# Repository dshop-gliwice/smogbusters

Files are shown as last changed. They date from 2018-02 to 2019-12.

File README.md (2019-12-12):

# smogbusters
Air monitoring project

Links:
 - particulate matter (PM) map: http://smogbusters.org/
 - charts: http://grafana.smogbusters.org/dashboard/db/measurements?refresh=10s&orgId=1
 - list of components: [bom.md](./docs/bom.md)

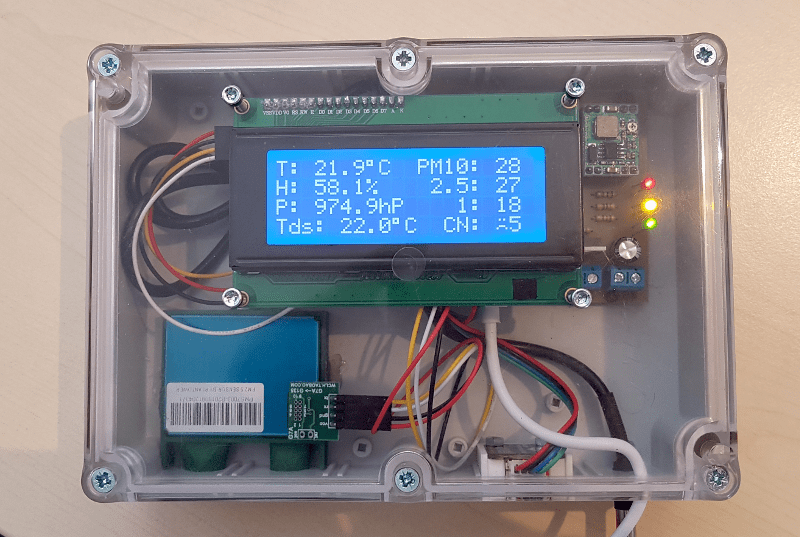
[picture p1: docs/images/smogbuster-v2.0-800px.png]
smogbusters-prototype


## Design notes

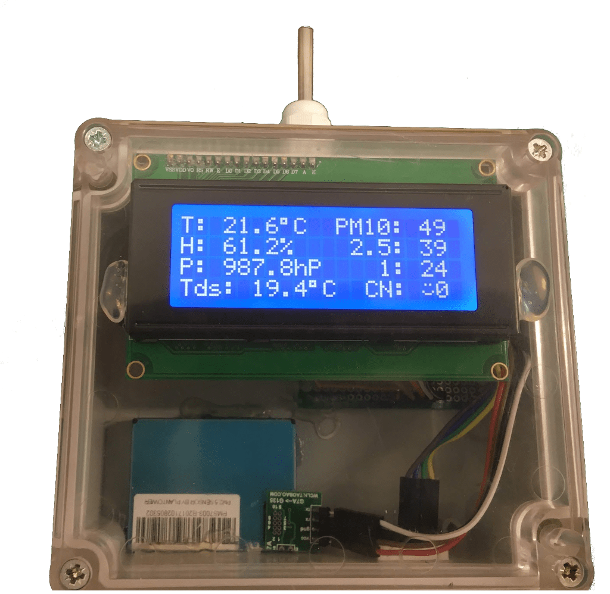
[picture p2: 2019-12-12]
docs/images/smogbuster-prototype.png

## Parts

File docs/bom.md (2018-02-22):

# smogbusters
Air monitoring project

* NodeMCU
  * https://www.aliexpress.com/item/1PCS-New-Wireless-Module-NodeMcu-Lua-WIFI-Internet-of-Things-development-board-based-ESP8266-with-pcb/32786565171.html
  * https://botland.com.pl/moduly-wifi/4450-modul-wifi-esp8266-nodemcu-v2-4mb.html
  * https://kamami.pl/moduly-wifi/559667-modul-z-esp8266-nodemcu.html

* Case
  * https://maszczyk.pl/pokaz_produkt/obudowy-hermetyczne-z-74.html

* Mosfet IRLZ44N
  * https://www.aliexpress.com/item/10PCS-IRLZ44N-IRLZ44-TO-220-TO220-IRLZ44NPBF/32845164480.html
  * https://botland.com.pl/n-mosfet/1950-n-mosfet-irlz44n-tht.html?search_query=IRLZ44N&results=1

* DC Power Supply Socket Female - 5.5 x 2.1mm
  * https://www.aliexpress.com/item/10Pcs-5-5-x-2-1mm-DC-Power-Supply-Jack-Socket-Female-Panel-Mount-3-Pin/32826223303.html
  * https://botland.com.pl/przewody-i-zlacza-zasilajace/9352-gniazdo-dc-55-x-21mm-do-obudowy.html

* 15 Pin Female Single Row Straight Header Strip 2.54mm Pitch  
  * https://www.aliexpress.com/snapshot/0.html?productId=1801736539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

* ARK connector
  * https://www.aliexpress.com/item/20pcs-KF301-2-Pin-Screw-Terminal-Block-Connector-5mm-Pitch-B/32735166786.html
  * https://botland.com.pl/zlacza-ark/810-zlacze-kf301-raster-5-mm-2-pin-.html

* Wires
  * https://botland.com.pl/przewody-polaczeniowe/2713-przewod-zensko-zenski-4-pin-20cm.html

* Power supply
  * https://www.aliexpress.com/item/S103-1pc-New-AC-100-240V-to-DC-5V-2A-Switching-Power-Supply-Converter-Adapter-EU/2002134601.html

* BME280
  * https://www.aliexpress.com/item/BME280-Digital-Sensor-Temperature-Humidity-Barometric-Pressure-Sensor-Breakout-Module-BME280-I2C-SPI-1-8-5V/32835514108.html
  * https://botland.com.pl/czujniki-temperatury/165-czujnik-temperatury-ds18b20-cyfrowy-1-wire-tht.html
  * https://kamami.pl/czujniki-temperatury/565661-bme280-czujnik-temperatury-wilgotnosci-oraz-barometr-modul-gravity-sen0236.html

* DS18B20
  * https://www.aliexpress.com/item/new-and-original-DS18B20-18B20-TO-92-3-Digital-Thermometer-Sensor/32716051460.html
  * https://kamami.pl/temperatury/138578-ds18b20.html

* PLANTOWER Laser DUST SENSOR PMS7003  
  * https://www.aliexpress.com/item/PLANTOWER-Laser-PM2-5-DUST-SENSOR-PMS7003-G7-High-precision-laser-dust-concentration-sensor-digital-dust/32639894148.html
  * https://kamami.pl/czujniki-gazow/564008-plantower-pms7003-laserowy-czujnik-pylu-pm25.html

* IDC adapter
  * https://kamami.pl/zlacza-inne/564553-adapter-idc10-127mm-na-zlacze-254mm-dla-czujnika-pms7003.html

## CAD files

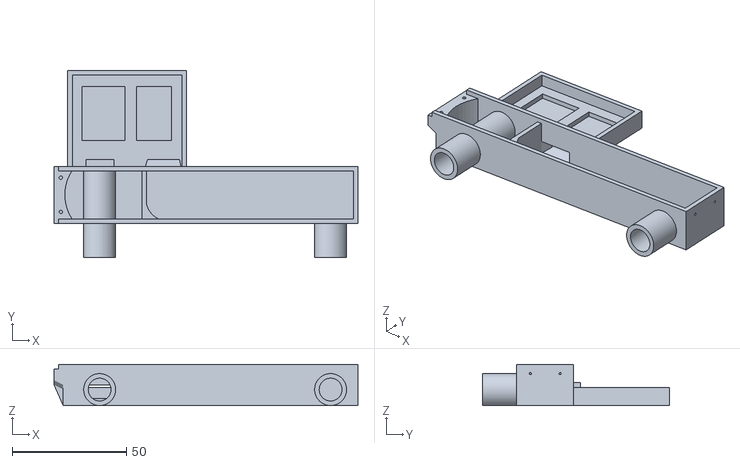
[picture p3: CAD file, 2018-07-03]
parts/Smog_buster_v1_35_main.stl
133.2 x 82.0 x 18.0

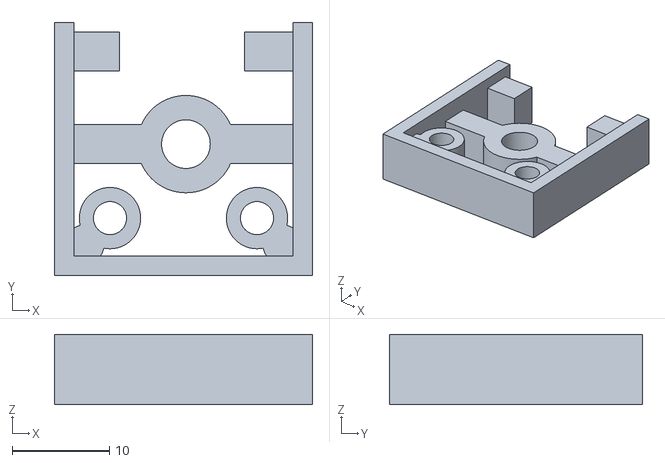
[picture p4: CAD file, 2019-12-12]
parts/bme280-dfrobot.stl
26.5 x 26.0 x 7.20

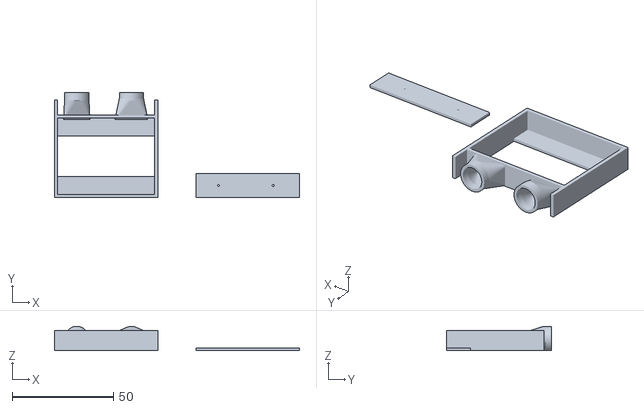
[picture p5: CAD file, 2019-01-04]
parts/pms7003.stl
121.0 x 52.0 x 12.0

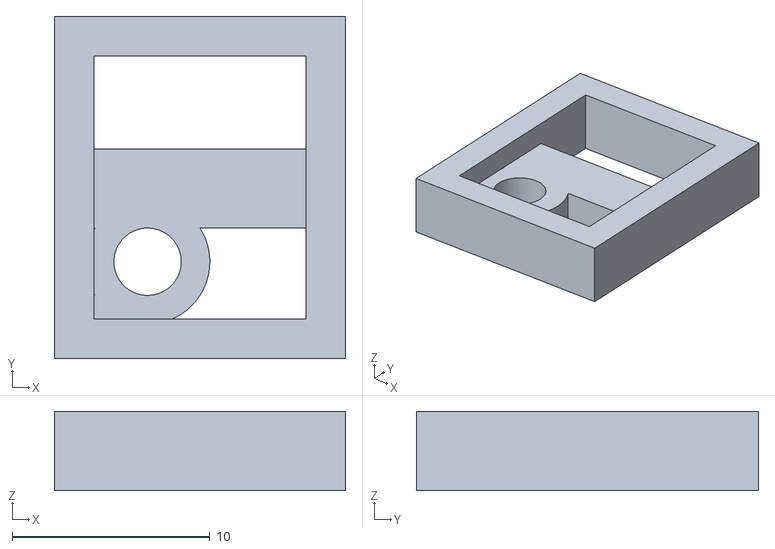
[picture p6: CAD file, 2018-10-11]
parts/bme280-narrow.stl
14.7 x 17.3 x 4.00

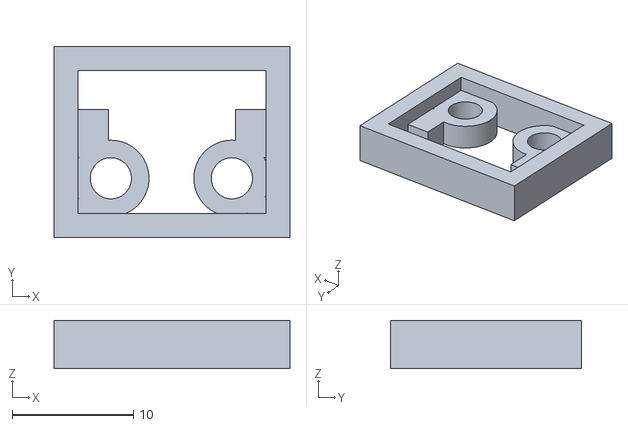
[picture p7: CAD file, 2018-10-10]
parts/bme280-wide.stl
19.5 x 15.8 x 4.00

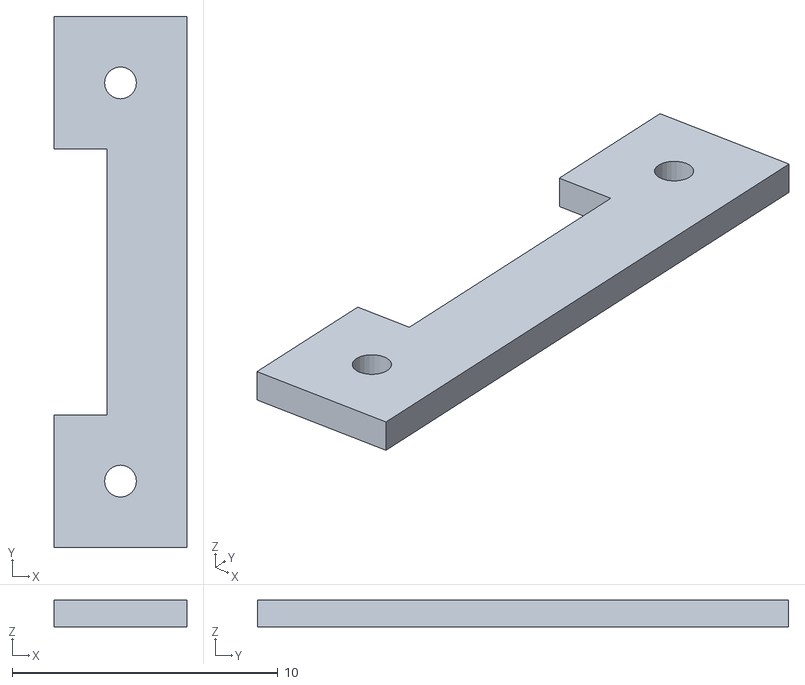
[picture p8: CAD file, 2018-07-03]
parts/Smog_buster_v1_35_zaczep.stl
5.00 x 20.0 x 1

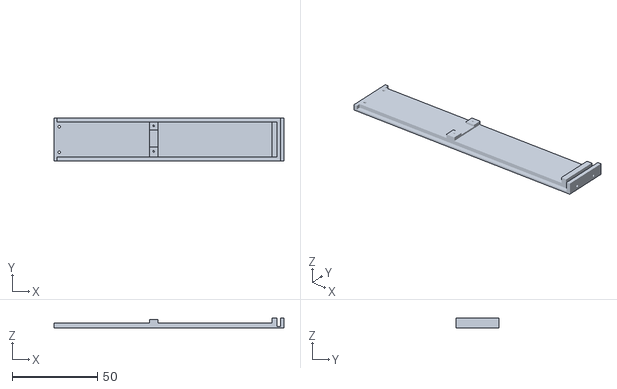
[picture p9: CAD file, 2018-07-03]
parts/Smog_buster_v1_35_klapka.stl
135.0 x 25.0 x 6.00

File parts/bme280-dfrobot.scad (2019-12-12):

$fn=64;

sHeight=7.2;
zOffset=0;

module screwMount(){
  difference(){
      cylinder(h = sHeight-1.5,
           d = 6.3  ,
           center = false);
      cylinder(h = sHeight,
           d = 3.4,
           center = false);
  } 
}

module spacer(){
    cube([5.5, 4, sHeight-1.5], false);  
}

module screwMountFill(){
    cylinder(h = sHeight-1.5,
           d = 4,
           center = false);
}


module main(){
  union(){

   //screw mounts
   translate([5.7, 5.9, zOffset])
     screwMount();
   translate([20.8, 5.9, zOffset])
     screwMount();

    //sensor channel
    difference(){
     union(){
       translate([1.2, 11.5, zOffset])
         cube([24,4,sHeight-2.5],false);
       translate([13.5, 13.5, zOffset])
         cylinder(h = sHeight-2.5,
           d = 10  ,
           center = false);
      }
      translate([13.5, 13.5, zOffset])
        cylinder(h = sHeight-1.3,
           d = 5,
           center = false);
    } 


   //screw mounts connections
   translate([3.1, 3.2, zOffset])
    screwMountFill();
   translate([23.4, 3.2, zOffset])
    screwMountFill();
    
   //back spacers
   translate([1.2, 21, zOffset])
    spacer();
   translate([19.5, 21, zOffset])
    spacer();
    
   //front wall
   translate([0, 0, zOffset])
    cube([26,2,sHeight],false);

   //side walls
   translate([0, 0, zOffset])
    cube([2, 26, sHeight],false);    
   translate([24.5, 0, zOffset])
    cube([2, 26, sHeight],false); 
  }  
}


main();

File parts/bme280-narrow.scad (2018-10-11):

$fn=64;

wHeight=4; //wall height
wThick=2; //wall thickness
bWidth=10.7; //board width
bHeight=13.3; //board height

module screwMount(){
  difference(){
    cylinder(h = wHeight-1.5,
             d = 6.3,
        center = false);
    cylinder(h = wHeight-1.3,
             d = 3.4,
        center = false);
  } 
}

module spacer(){
  cube([bWidth, 4, wHeight-1.5],false);  
}

module screwMountFill(){
  cylinder(h = wHeight-1.5,
           d = 2,
      center = false);
}

module main(){
  union(){
    //screw mounts
    translate([wThick+2.7, wThick+2.9, 0])
      screwMount();

    //screw mounts connections
    translate([wThick+0.6, wThick+0.4, 0])
      screwMountFill();
        
    //back spacer
    translate([wThick, wThick+4.6, 0])
      spacer();

    //front wall
    translate([0, 0, 0])
      cube([wThick*2+bWidth, wThick, wHeight], false);
    //back wall
    translate([0, wThick+bHeight, 0])
      cube([wThick*2+bWidth, wThick, wHeight], false);

    //side walls
    translate([0, 0, 0])
      cube([wThick, wThick+bHeight, wHeight], false);    
    translate([wThick+bWidth, 0, 0])
      cube([wThick, wThick+bHeight, wHeight], false);
  }  
}


main();

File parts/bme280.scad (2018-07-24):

$fn=64;

sHeight=7.2;

module screwMount(){
  difference(){
      cylinder(h = sHeight-1.5,
           d = 6.3,
           center = false);
      cylinder(h = sHeight-1.3,
           d = 3.4,
           center = false);
  } 
}

module spacer(){
    cube([5.5,4,sHeight-1.5],false);  
}

module screwMountFill(){
    cylinder(h = sHeight-1.5,
           d = 4,
           center = false);
}


module main(){
  union(){
   //screw mounts
   translate([5.4, 5.6, 0])
    screwMount();
   translate([20.6, 5.6, 0])
    screwMount();
    
   //screw mounts connections
   translate([2.9, 3, 0])
    screwMountFill();
   translate([23.1, 3, 0])
    screwMountFill();
    
   //back spacers
   translate([1.2,21,0])
    spacer();
   translate([19,21,0])
    spacer();
    
   //front wall
   translate([0,0,0])
    cube([26,2,sHeight],false);

   //side walls
   translate([0,0,0])
    cube([2,26,sHeight],false);    
   translate([24,0])
    cube([2,26,sHeight],false);
  }  
}


main();

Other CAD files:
parts/bme280-wide.scad
parts/pms7003.scad

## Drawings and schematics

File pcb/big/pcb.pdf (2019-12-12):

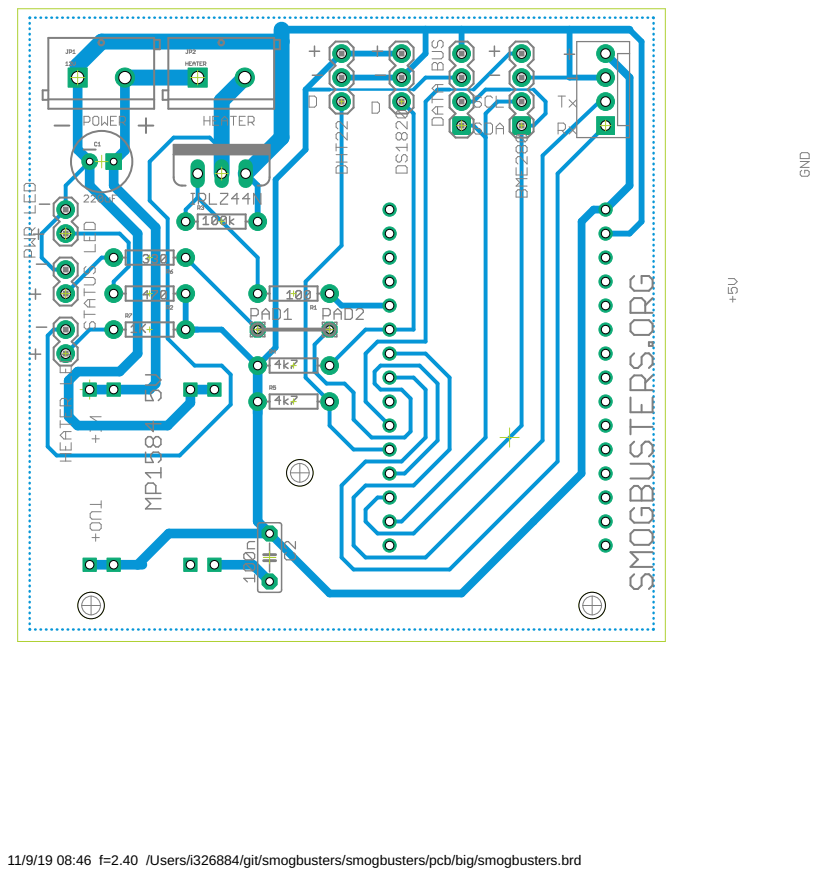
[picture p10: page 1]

11/9/19 08:46 f=2.40 /Users/i326884/git/smogbusters/smogbusters/pcb/big/smogbusters.brd

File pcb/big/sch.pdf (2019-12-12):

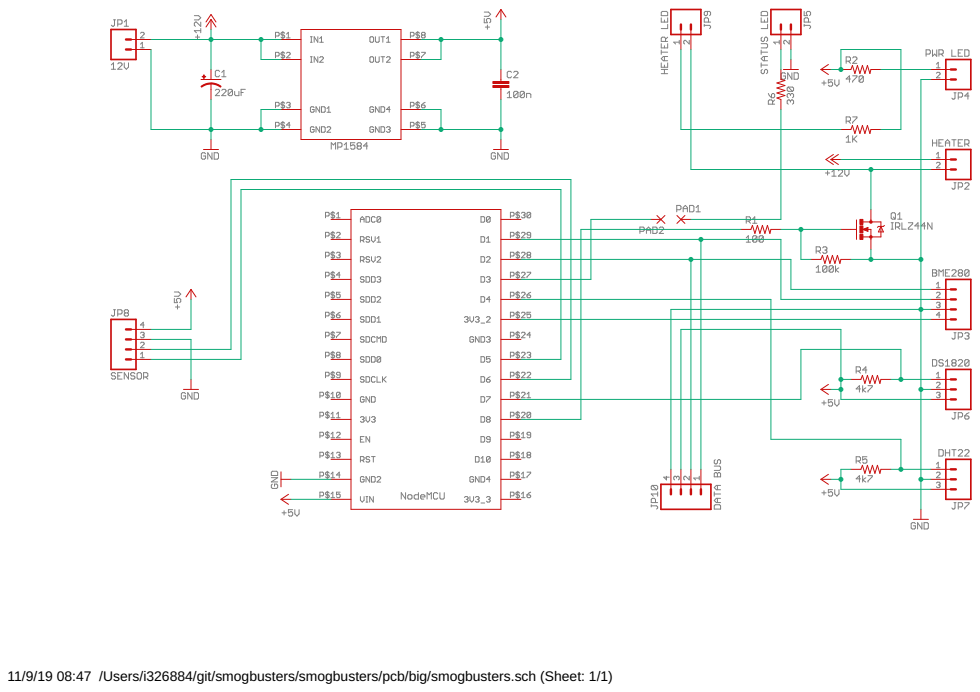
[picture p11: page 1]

11/9/19 08:47 /Users/i326884/git/smogbusters/smogbusters/pcb/big/smogbusters.sch (Sheet: 1/1)

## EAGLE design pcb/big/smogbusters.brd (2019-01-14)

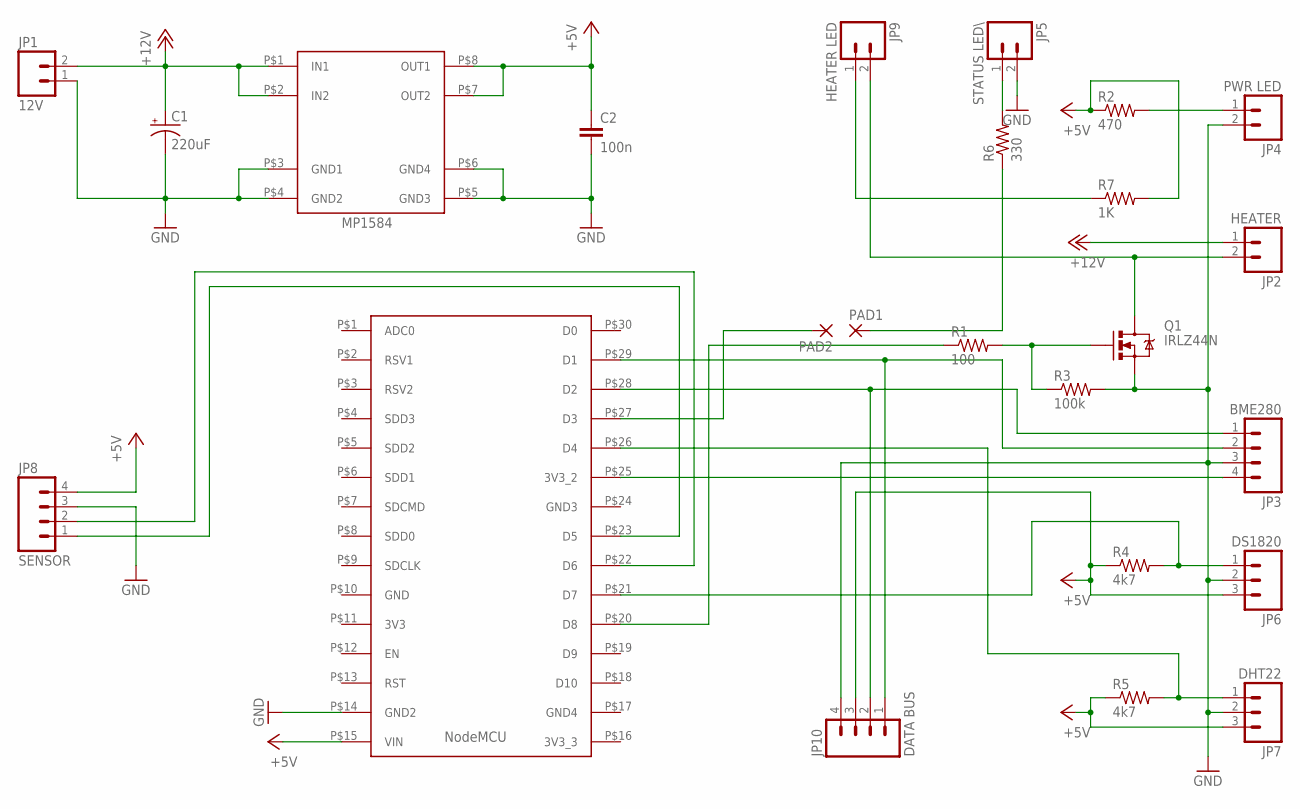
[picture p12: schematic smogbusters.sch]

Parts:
C1: 220uF; CPOL-RADIAL-100UF-25V
C2: 100n; C5B2.5
JP1: 12V; SCREWTERMINAL-5MM-2
JP2: HEATER; SCREWTERMINAL-5MM-2
JP3: BME280; 1X04
JP4: PWR LED; 1X02
JP5: STATUS LED\; 1X02
JP6: DS1820; 1X03
JP7: DHT22; 1X03
JP8: SENSOR; MOLEX-1X4
JP9: HEATER LED; 1X02
JP10: DATA BUS; 1X04
PAD1, PAD2: 1,6/0,8
Q1: IRLZ44N; TO220V
R1: 100; AXIAL-0.3
R2: 470; AXIAL-0.3
R3: 100k; AXIAL-0.3
R4, R5: 4k7; AXIAL-0.3
R6: 330; AXIAL-0.3
R7: 1K; AXIAL-0.3
U$1: NODEMCU
U$2: MP1584

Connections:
+5V: C2.1, JP6.3, JP7.3, JP8.4, JP10.3, R2.P$1 (1), R4.P$1 (1), R5.P$1 (1), R7.P$2 (2), U$1.P$15 (VIN), U$2.P$7 (OUT2), U$2.P$8 (OUT1)
+12V: C1.1 (+), JP1.2, JP2.1, U$2.P$1 (IN1), U$2.P$2 (IN2)
GND: C1.2 (-), C2.2, JP1.1, JP3.3, JP4.2, JP5.2, JP6.2, JP7.2, JP8.3, JP10.4, Q1.3 (S), R3.P$2 (2), U$1.P$14 (GND2), U$2.P$3 (GND1), U$2.P$4 (GND2), U$2.P$5 (GND3), U$2.P$6 (GND4)
unnamed: JP2.2, JP9.2, Q1.2 (D)
unnamed: JP6.1, R4.P$2 (2), U$1.P$21 (D7)
unnamed: Q1.1 (G), R1.P$2 (2), R3.P$1 (1)
unnamed: JP5.1, R6.P$2 (2)
unnamed: JP3.4, U$1.P$25 (3V3_2)
unnamed: JP8.1, U$1.P$23 (D5)
unnamed: JP8.2, U$1.P$22 (D6)
unnamed: R1.P$1 (1), U$1.P$20 (D8)
unnamed: JP7.1, R5.P$2 (2), U$1.P$26 (D4)
unnamed: PAD1.1, R6.P$1 (1)
unnamed: JP9.1, R7.P$1 (1)
unnamed: PAD2.1, U$1.P$27 (D3)
unnamed: JP4.1, R2.P$2 (2)
unnamed: JP3.1, JP10.2, U$1.P$28 (D2)
unnamed: JP3.2, JP10.1, U$1.P$29 (D1)

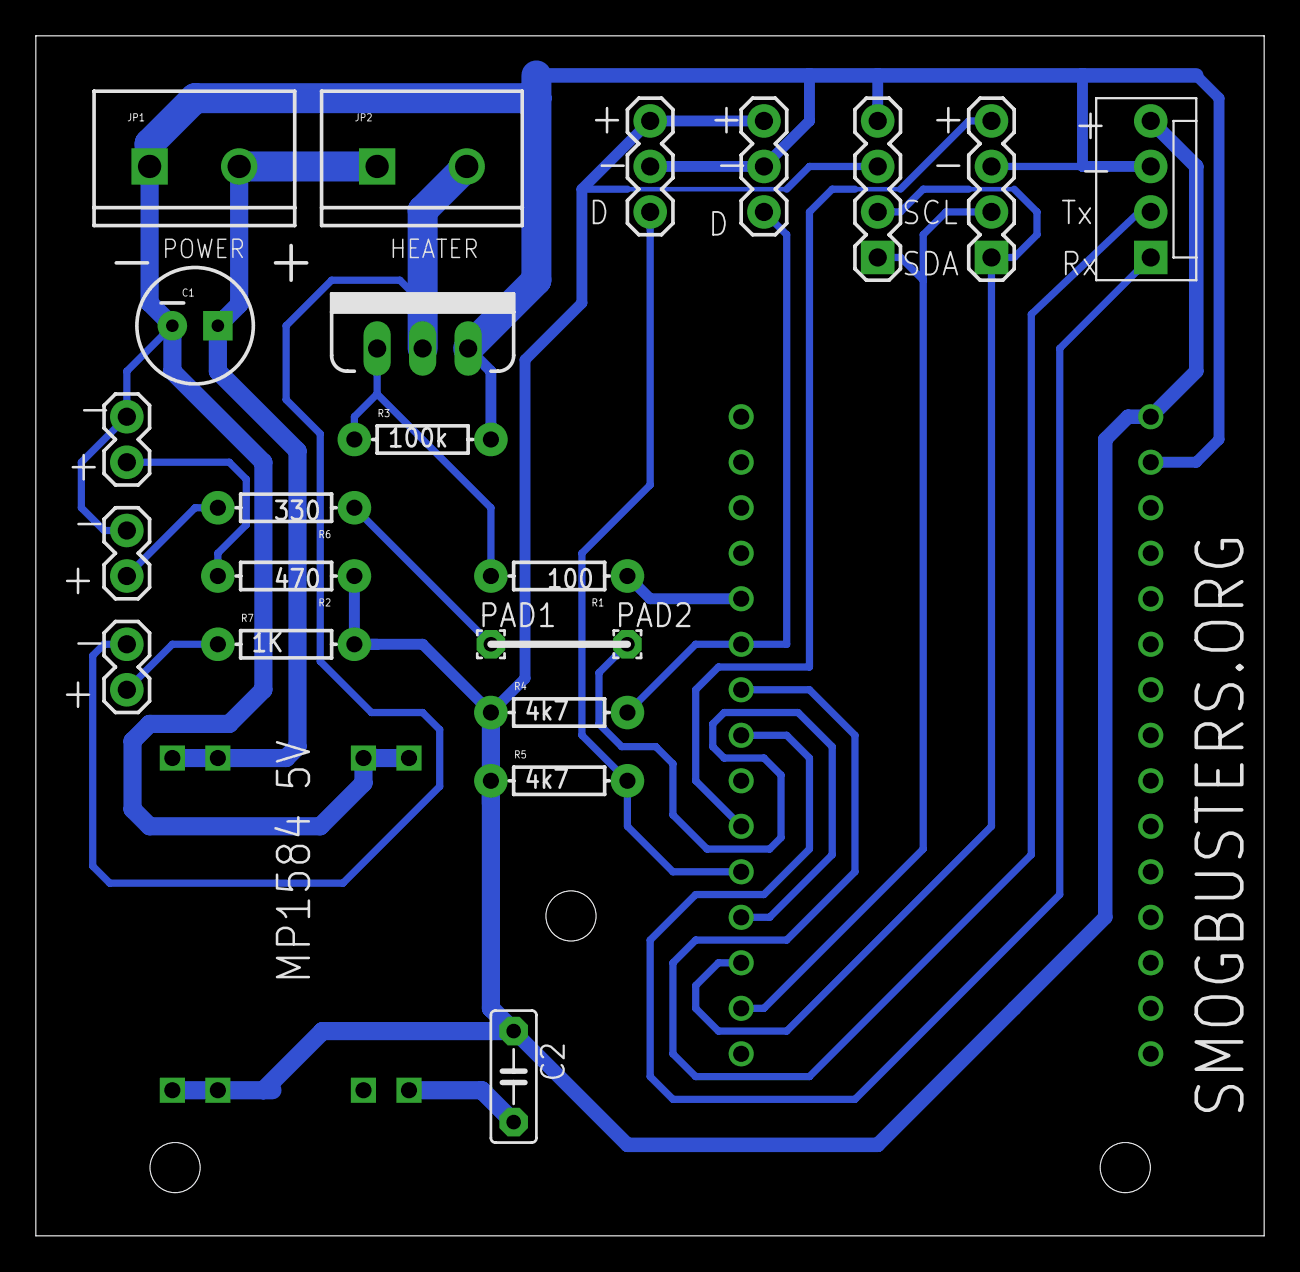
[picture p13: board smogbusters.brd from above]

Board: 1 copper layer, 68.6 x 67.0 mm, 24 parts (1 on the bottom side), 18 nets.

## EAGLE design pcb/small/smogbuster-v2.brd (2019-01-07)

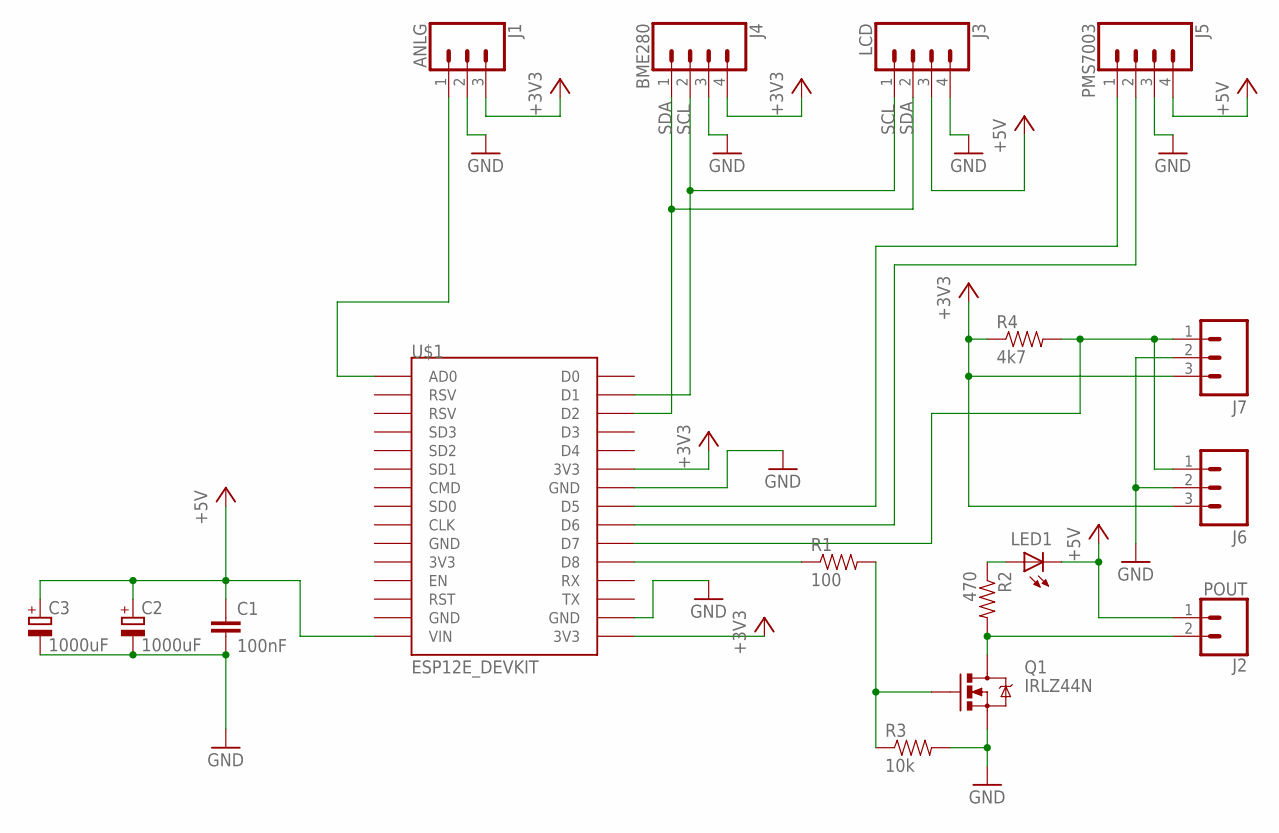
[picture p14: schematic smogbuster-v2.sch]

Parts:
C1: 100nF; CAP-PTH-5MM
C2, C3: 1000uF; E2,5-7
J1: ANLG; 1X03
J2: POUT; 1X02
J3: LCD; 1X04
J4: BME280; 1X04
J5: PMS7003; 1X04
J6, J7: M03PTH; 1X03
LED1: LED3MM
Q1: IRLZ44N; TO220V
R1: 100; AXIAL-0.3
R2: 470; AXIAL-0.3
R3: 10k; AXIAL-0.3
R4: 4k7; AXIAL-0.3
U$1: ESP12E_DEVKIT

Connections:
+3V3: J1.3, J4.4, J6.3, J7.3, R4.P$1 (1), U$1.3V3@1 (3V3), U$1.3V3@2 (3V3)
+5V: C1.1, C2.+, C3.+, J2.1, J3.3, J5.4, LED1.K (C), U$1.VIN
DQ: J6.1, J7.1, R4.P$2 (2), U$1.D7
GND: C1.2, C2.-, C3.-, J1.2, J3.4, J4.3, J5.3, J6.2, J7.2, Q1.3 (S), R3.P$2 (2), U$1.GND@2 (GND), U$1.GND@3 (GND)
unnamed: J2.2, Q1.2 (D), R2.P$2 (2)
unnamed: Q1.1 (G), R1.P$2 (2), R3.P$1 (1)
unnamed: J1.1, U$1.AD0
unnamed: R1.P$1 (1), U$1.D8
unnamed: LED1.A, R2.P$1 (1)
RX: J5.1, U$1.D5
SCL: J3.1, J4.2, U$1.D1
SDA: J3.2, J4.1, U$1.D2
TX: J5.2, U$1.D6

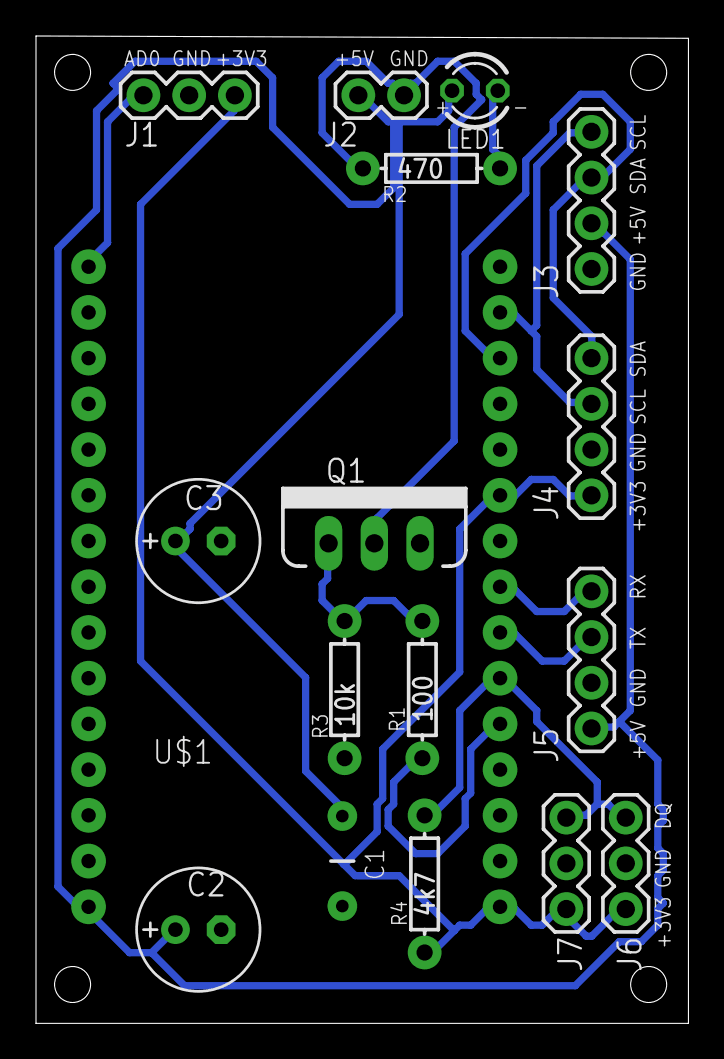
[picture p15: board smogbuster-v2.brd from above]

Board: 1 copper layer, 36.2 x 54.9 mm, 17 parts (0 on the bottom side), 13 nets.

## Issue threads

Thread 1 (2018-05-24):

List of issues with PCB

adamwalach, 2018-05-24:
- DC2DC converter is mounted upside-down
- connectors for BME280, DS1820, DHT22 are covered by nodemcu
- change value of resistors green led (power) - 470, yellow (status) - 470
- fix pins labels for BME280
- change pin for status LED to D3 - we cannot use A0 as a digital output
- for the "DATA BUS" connector use the same pins as for BME280 (D1, D2)

adamwalach, 2018-10-02:
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

Closed 2019-12-16.

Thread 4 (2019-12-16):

Control LCD backlight with motion sensor

adamwalach, 2019-12-16:
With sensor like [HC-SR501](https://www.aliexpress.com/item/4000202877086.html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,searchweb201602_3,searchweb201603_53) or similar we could control the LCD backlight. That would make our device more friendly for in-door use.
AC:
- connect HC-SR501 to an unused input pin from NodeMCU
- add support for it in the code so every time motion is detected the LCD backlight will be turned on (by a command - we do not need to add any additional hardware)

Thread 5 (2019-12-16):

Turn ON particulate matter sensor only when it is needed

adamwalach, 2019-12-16:
PMS 7003 (particulate matter sensor) should be turned on/powered on only when its needed - this way we can extend lifetime of the laser diode.
We could use the high power output that was originally designed to control heater. The problem is that it connects to the ground terminal. That may not work.

AC:
 - PMS7003 is powered on (diode and fan) only when it is needed - before the measurement is about to be taken (or with some additional delay so it provides a stable readout)

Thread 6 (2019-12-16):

Protect input and output channels of particulate matter sensor

adamwalach, 2019-12-16:
Input and output channels are about 10 mm in size - that is enough for some insects to get inside and build a warm and cozy nest. We would like to avoid that.
We could use a piece of [mosquito net](https://www.castorama.pl/siatka-na-okno-bros-fx-100-x-100-cm-czarna-id-44377.html) and 3d-printed adapter to cover the channels.

AC:
- channels are protected
- no regression to sensor sensitivity

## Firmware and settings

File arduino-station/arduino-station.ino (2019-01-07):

#include <EEPROM.h>
#include <ESP8266WiFi.h>
#include <ESP8266HTTPClient.h>
#include "Timer.h"


#define READ_CYCLE 10000

#define UUID_LENGTH 25
#define FW_VERSION "18.12.03-a"

Timer timer;

struct MeasurementId {
  char uuid[UUID_LENGTH];
  char sensors [10];      
};
  
struct MeasurementData {
  float temp;
  float humidity;
  float pressure;
  int pm25;
  int pm10;
  int pm1;
  float DStemp;
  char firmware [15];
};

struct Measurement {
  char version [5];
  struct MeasurementId id;
  struct MeasurementData data;
};

struct PmsData {
  int pm1;
  int pm25;
  int pm10;
};

void setup() {
  randomSeed(analogRead(0));
  EEPROM.begin(512);
  initializeSerial();
  checkContext();
  initializeStatusLed();
  initializeHeater();
  initializeSensors();
  initializeLCD();
  initClient();
  initOTA();
}

void loop() {
  serialLoop();
  timer.update();
}

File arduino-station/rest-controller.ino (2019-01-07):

#include <ESP8266WiFi.h>
#include <ESP8266HTTPClient.h>
#include <ArduinoJson.h>

const char* gatewayUrl = "http://api.smogbusters.org/api/measurement";

unsigned long sendCount = 0;
unsigned long sendCountFailed = 0;

void initClient() {
    Serial.println();
    Serial.print("Gateway url: ");
    Serial.println(gatewayUrl);
    Serial.print("MAC: ");
    Serial.println(WiFi.macAddress());
    Serial.print("FW version: ");
    Serial.println(FW_VERSION);

    Serial.print("Connecting to ");
    Serial.println(ctx.wifiSSID);

    Serial.flush();

    WiFi.mode(WIFI_STA);
    WiFi.begin(ctx.wifiSSID, ctx.wifiPasswd);

    int i=0;
    while (WiFi.status() != WL_CONNECTED && i<40) {
      blinkStatusLed();
      Serial.print(".");
      i++;
    }
    
    if (WiFi.status() == WL_CONNECTED){
      Serial.println("WIFI connected");
      Serial.print("IP address: ");
      Serial.println(WiFi.localIP());
      enableStatusLed();
    }else{
      Serial.println("WIFI is NOT connected");
    }
}

bool sendMeasurement(Measurement * msr, size_t memSize) {
    //Prepare data
    DynamicJsonBuffer jsonBuffer(memSize);

    JsonObject& json = jsonBuffer.createObject();
    json["version"] = msr->version;

    JsonObject& idField = json.createNestedObject("id");
    idField["uuid"] = msr->id.uuid;
    idField["sensors"] = msr->id.sensors;

    JsonObject& dataField = json.createNestedObject("data");
    dataField["temp"] = msr->data.temp;
    dataField["humidity"] = msr->data.humidity;
    dataField["pressure"] = msr->data.pressure;
    dataField["pm25"] = msr->data.pm25;
    dataField["pm10"] = msr->data.pm10;
    dataField["pm1"] = msr->data.pm1;
    dataField["DStemp"] = msr->data.DStemp;
    dataField["free_heap"] = ESP.getFreeHeap();
    dataField["cnt"] = sendCount;
    dataField["cnt_failed"] = sendCountFailed;
    dataField["heater_state"] = getHeaterState();
    dataField["firmware"] = msr->data.firmware;

    String payload;
    json.printTo(payload);
    Serial.println(payload);
    Serial.flush();
    
    // Send data
    if(WiFi.status() != WL_CONNECTED){
      return false;
    }

    HTTPClient client;
    client.begin(gatewayUrl);
    client.addHeader("Content-Type", "application/json");

    int httpCode = client.POST(payload);
    Serial.println("Request sent");
    if (httpCode != HTTP_CODE_OK) {
      Serial.printf("Request failed, error: %s\n", client.errorToString(httpCode).c_str());
      return false;
    }

    client.end();
    return true;
}

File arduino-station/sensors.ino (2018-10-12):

#define DS1820_INITDELAY 100

void initializeSensors() {
  delay(100);
  initializeBME();
  initializePMS();
  if(initializeDS()) {
    timer.after(DS1820_INITDELAY, requestDS1820);
  }
  timer.every(READ_CYCLE, readAndSend);
}

void readAndSend() {
  sendCount++;
  MeasurementData data = readMeasurementFromBME();
  PmsData pmsData = pmsLoop();
  strcpy(data.firmware, FW_VERSION);
  data.pm25 = pmsData.pm25;
  data.pm10 = pmsData.pm10;
  data.pm1 = pmsData.pm1;
  data.DStemp = DStemp;
  Measurement measurement = {"1", {"uuid", "BME280"}, data};
  memcpy( measurement.id.uuid, ctx.deviceID, UUID_LENGTH*sizeof(char));
  bool msrSent = sendMeasurement(&measurement, sizeof(measurement));
  if (!msrSent) {
    Serial.println("Could not send the measurement");
    sendCountFailed++;
    if (sendCountFailed > 9) {
      disableStatusLed();
      Serial.println("Too many failed attempts. Rebooting");
      delay(500);
      ESP.restart();
     }
  }else{
    sendCountFailed=0;
  }

  updateLCD(&measurement);
  updateHeater(&measurement);
  
  blinkStatusLed();
  if (msrSent) {
    enableStatusLed();
  }else{
    disableStatusLed();
  }
}

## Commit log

2017-03-23 Add BME280 sensor support
2017-04-05 add debug data, fix url
    [rest-controller.ino]
2017-04-13 DS1820 support - pin D7
2017-04-23 Heater definition
2018-02-22 First version of BOM
2018-03-08 Add pcb
    [smogbusters.brd, smogbusters.sch]
2018-07-03 improve 3d printed parts
    [Smog_buster_v1_35_klapka.stl, Smog_buster_v1_35_main.stl, Smog_buster_v1_35_zaczep.stl]
2018-07-23 Add case for bme280
    [bme280.scad]
2018-07-23 Fix case for bme280
    [bme280.scad]
2018-07-24 bme280 case update
    [bme280.scad, bme280.stl]
2018-07-25 Add support for status led
2018-09-26 Adapter for bme280 by dfrobot
    [dfrobot-bme280.scad, dfrobot-bme280.stl]
2018-09-26 Bulk upgrade
    This should be divided into multiple commits. Sorry…
    - lcd support
    - settings for wifi and bme280 are now stored in eeprom
    - extended serial commands
    - cleanup
2018-10-01 Heater - working copy. TODO - safe fallback when no sensor is present or sensor is broken
    [eeprom.ino, heater.ino, serial.ino]
2018-10-03 Working heater, PMS library used
2018-10-03 Add heaterVoltage to eeprom
2018-10-10 Add new adapters for BME280
    [bme280-dfrobot.scad, bme280-dfrobot.stl, bme280-narrow.scad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]
2018-10-11 Improve handling of disconnected sensors
2018-10-11 Fix adapter for bme280-narrow
    [bme280-narrow.scad, bme280-narrow.stl]
2018-11-18 Add case for pms7003
    [pms7003.scad]
2018-11-19 Add drill template
    [pms7003.scad]
2018-12-02 Improve case for pms7003
    [pms7003.scad, pms7003.stl]
2019-01-04 Fix var names
    [pms7003.scad, pms7003.stl]
2019-01-07 Add smaller version of PCB
    [DRILEGEND.CFG, smogbuster-v2.brd, smogbuster-v2.sch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]
2019-01-14 PCB fixes acc. to ticket #1
    [smogbusters.brd, smogbusters.sch]
2019-11-06 Production PCB
2019-12-12 Improve bme280-dfrobot adapter
    [bme280-dfrobot.scad, bme280-dfrobot.stl]
2019-12-12 Add pdf preview for big pcb
2019-12-12 Add device assembly documentation

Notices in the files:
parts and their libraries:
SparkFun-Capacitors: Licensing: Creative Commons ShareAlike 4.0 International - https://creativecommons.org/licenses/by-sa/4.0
